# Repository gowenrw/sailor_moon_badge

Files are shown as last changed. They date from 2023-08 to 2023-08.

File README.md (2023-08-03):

# sailor_moon_badge

Sailor Moon Badge Artifacts

This is a DEFCON Indie badge created for DC31.

This is where all the files for the Badge will be stored.

This includes code and art and cad and fab files.  All the things.

## File Structure

This is the file structure of this repository

* [/](/README.md) - YOU ARE HERE
* [/art/](./art/) - Artwork and other graphics created by this project
  * [/art/inspiration/](./art/inspiration/) - Art and graphics pulled from other sources used as inspiration for this project
  * [/art/fonts/](./art/fonts/) - Fonts used in art and graphics
* [/code/](./code/) - All project related Code / Firmware
* [/docs/](./docs/) - Documentation created by this project including web pages
* [/eda/](./eda/) - Electronic Design Automation files (i.e. KiCad)
  * [/eda/sailor_moon/](./eda/sailor_moon/) - KiCad 6.x project folder for the future_badge PCB
* [/README.md](/README.md) - This File
* [/LICENSE](/LICENSE) - Currently set to MIT

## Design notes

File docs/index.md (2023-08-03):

---
layout: default
---

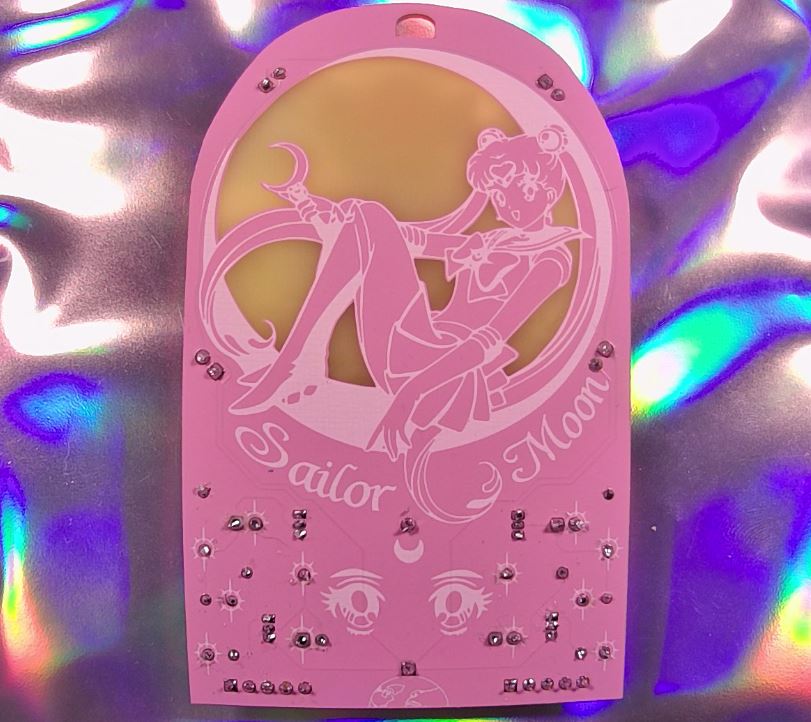
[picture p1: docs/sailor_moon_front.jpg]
sailor moon front


# Welcome

Welcome to the sailor moon badge website/repository.

This is where you will find all the details and files and instructions related to the DC31 sailor moon badge #badgelife.

# Story

I noticed at defcon 30 that there were no anime badges or cute badges I found appealing.

So, I wanted to make a cute sailor moon themed badge that was easy to assemble and could stand on its own to be displayed with figures and other collectables.

I think this badge turned out great and I hope everyone enjoys it.

-- Ninjician

---

# Details

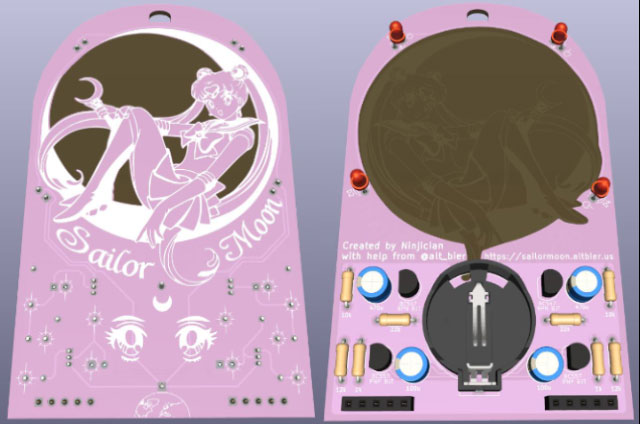
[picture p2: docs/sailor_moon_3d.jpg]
sailor moon 3d


The badge is designed with a simple easy to solder circuit that utilizes back lighting to highlight the art.

It uses female and male header pins on the bottom of the badge to make a stand that allows the badge to stand upright on a flat surface.

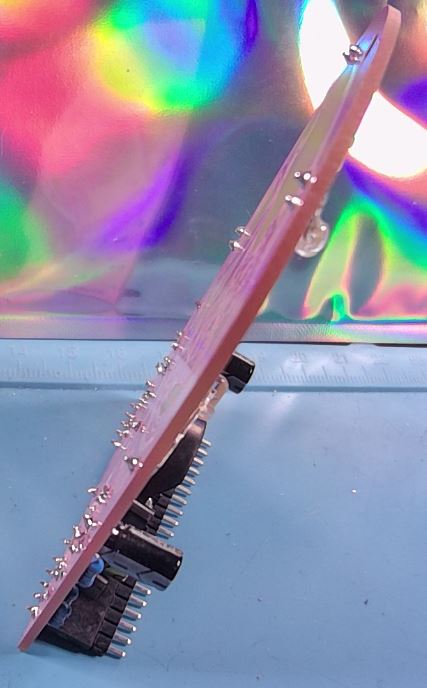
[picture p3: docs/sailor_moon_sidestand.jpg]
sailor moon side stand


While a few assembled badges will be available most will be provided as DIY solder kits.

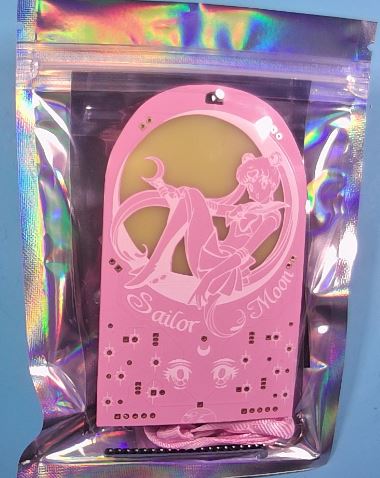
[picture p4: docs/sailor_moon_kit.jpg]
sailor moon kit


## The Circuit

The circuit is based on an astable multivibrator with the resistance and capacitance adjusted to produce the LED fade effect.

Here is the circuit schematic

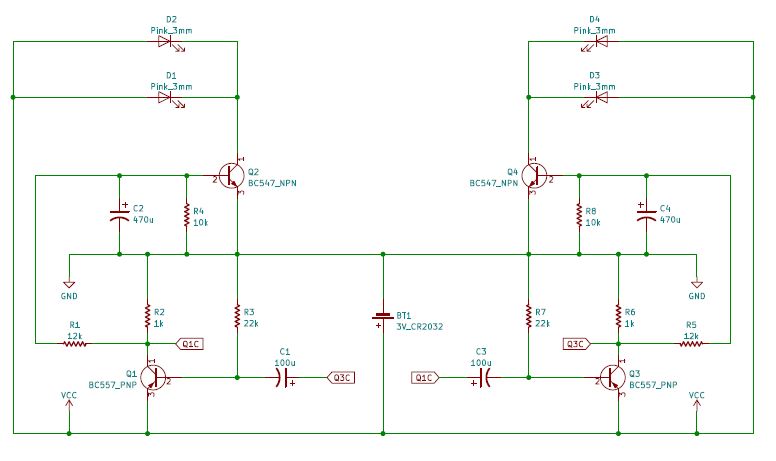
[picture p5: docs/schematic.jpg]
sailor moon schematic


## Kit Contents

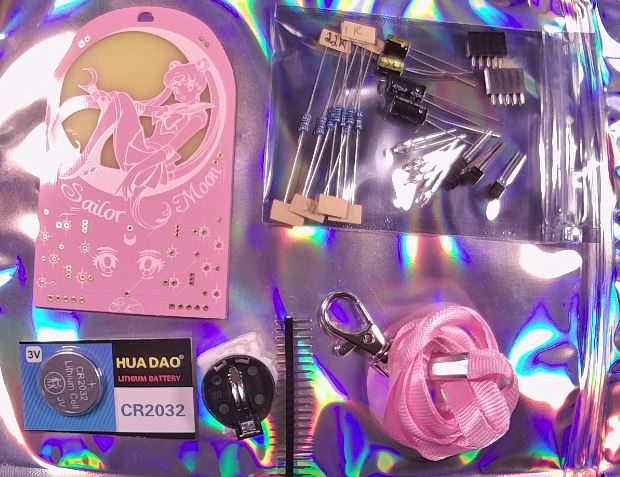
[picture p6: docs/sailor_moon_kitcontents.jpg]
sailor moon kit contents


The kit contains the following items:

* 1x PCB
* 1x Lanyard
* 1x 1x20 pin Male Header
* 1x CR2032 Battery Holder
* 1x CR2032 Battery
* 2x 1x5 pin Female Header
* 2x 22k ohm Resistor
* 2x 12k ohm Resistor
* 2x 10k ohm Resistor
* 2x 1k ohm Resistor
* 2x BC547 NPN BJT Transistor
* 2x BC557 PNP BJT Transistor
* 2x 100uF Polorized Capacitor
* 2x 470uF Polorized Capacitor
* 4x 3mm 2-pin Pink LED

# Kit Assembly

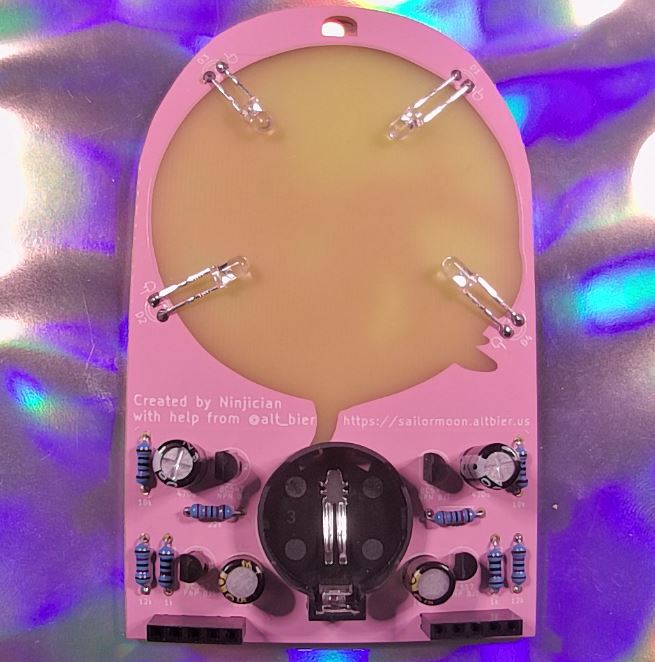
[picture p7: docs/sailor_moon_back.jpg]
sailor moon back


To assemble this badge you will place the through hole components into the pcb with the component body on the back of the pcb soldering the legs on the front of the pcb trimming them off at the top of the solder joints.

The back of the pcb has clear labels of where to place the components.

Take note of the direction of the transistors (which way the flat side faces) and make sure you place the proper transistor type in each space (the labels on the transistors are very small but are the only way to tell the difference between the two types).

Take note of the capacitor polarity inserting the negative leg into the negative hole which is indicated by solid silkscreen on the pcb.
The capacitors are labeled with the uF value and have a solid stripe on the negative leg side.

The resistors are bidirectional so it does not matter which way they are inserted as long as the proper resistance ohm value is used for each.  The pcb has the resistor values clearly labeled and while the resistors have a color code to show thier value, for your convinience the value has been written on the paper attached to them.

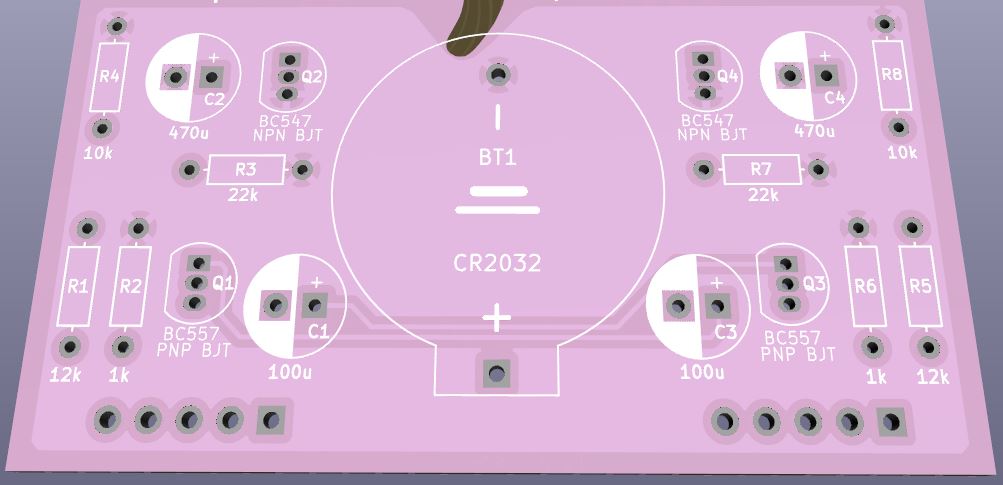
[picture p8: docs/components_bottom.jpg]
sailor moon components bottom


The LEDs should not be fully inserted instead leaving enough leg space for them to be bent over after soldering to appear in the back lit window of the pcb.

Take note of the direction of the LEDs as labeled on the PCB.  The label shows the short leg going into the square hole.

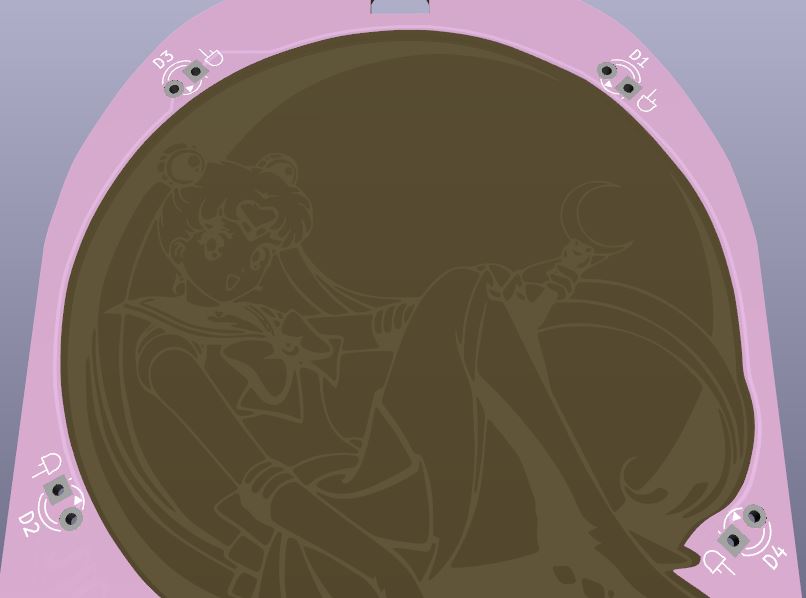
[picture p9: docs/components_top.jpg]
sailor moon components top


The female headers at the bottom are not part of the circuit and are thus optional.

The female headers allow for the insertion of the long male header strip to form a display stand for the badge.

# Repository

The repository containing all the artifacts for this badge is located [HERE](https://github.com/gowenrw/sailor_moon_badge)

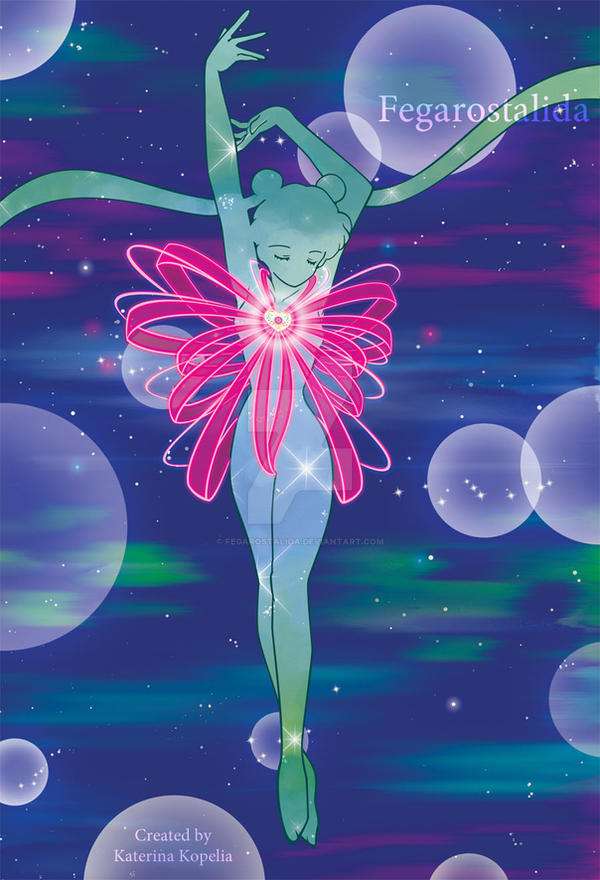
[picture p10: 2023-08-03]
art/inspiration/sailor_moon_supers_transformation_poster_by_fegarostalida_dc6exwj-fullview.jpg

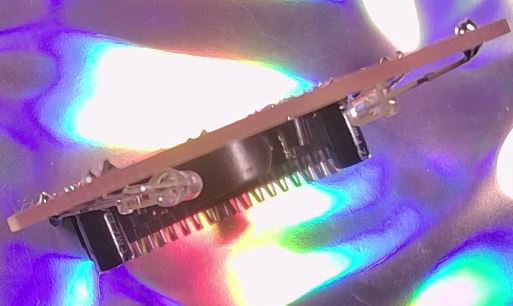
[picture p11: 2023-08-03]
docs/sailor_moon_topdown.jpg

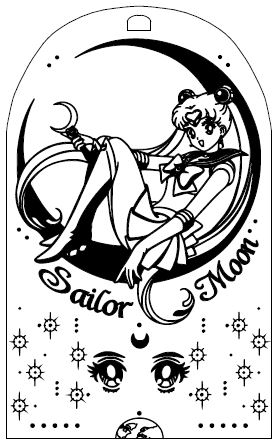
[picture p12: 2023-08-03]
docs/front_silk.jpg

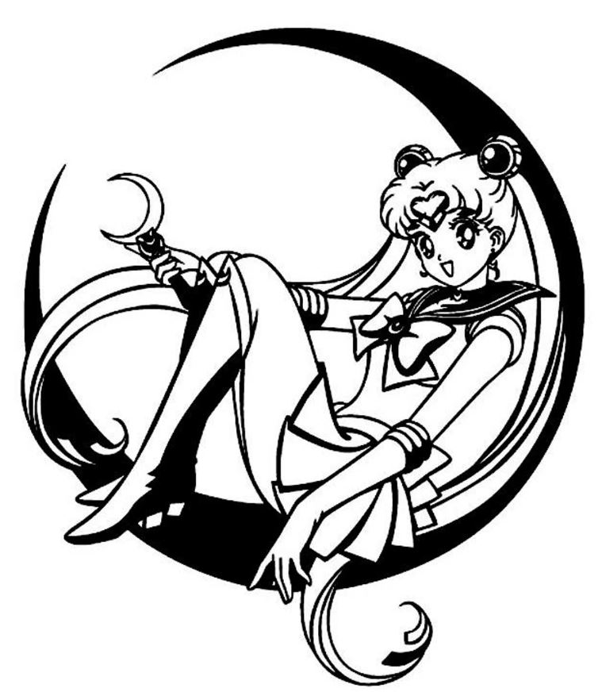
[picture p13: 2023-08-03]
art/inspiration/Circle.JPG

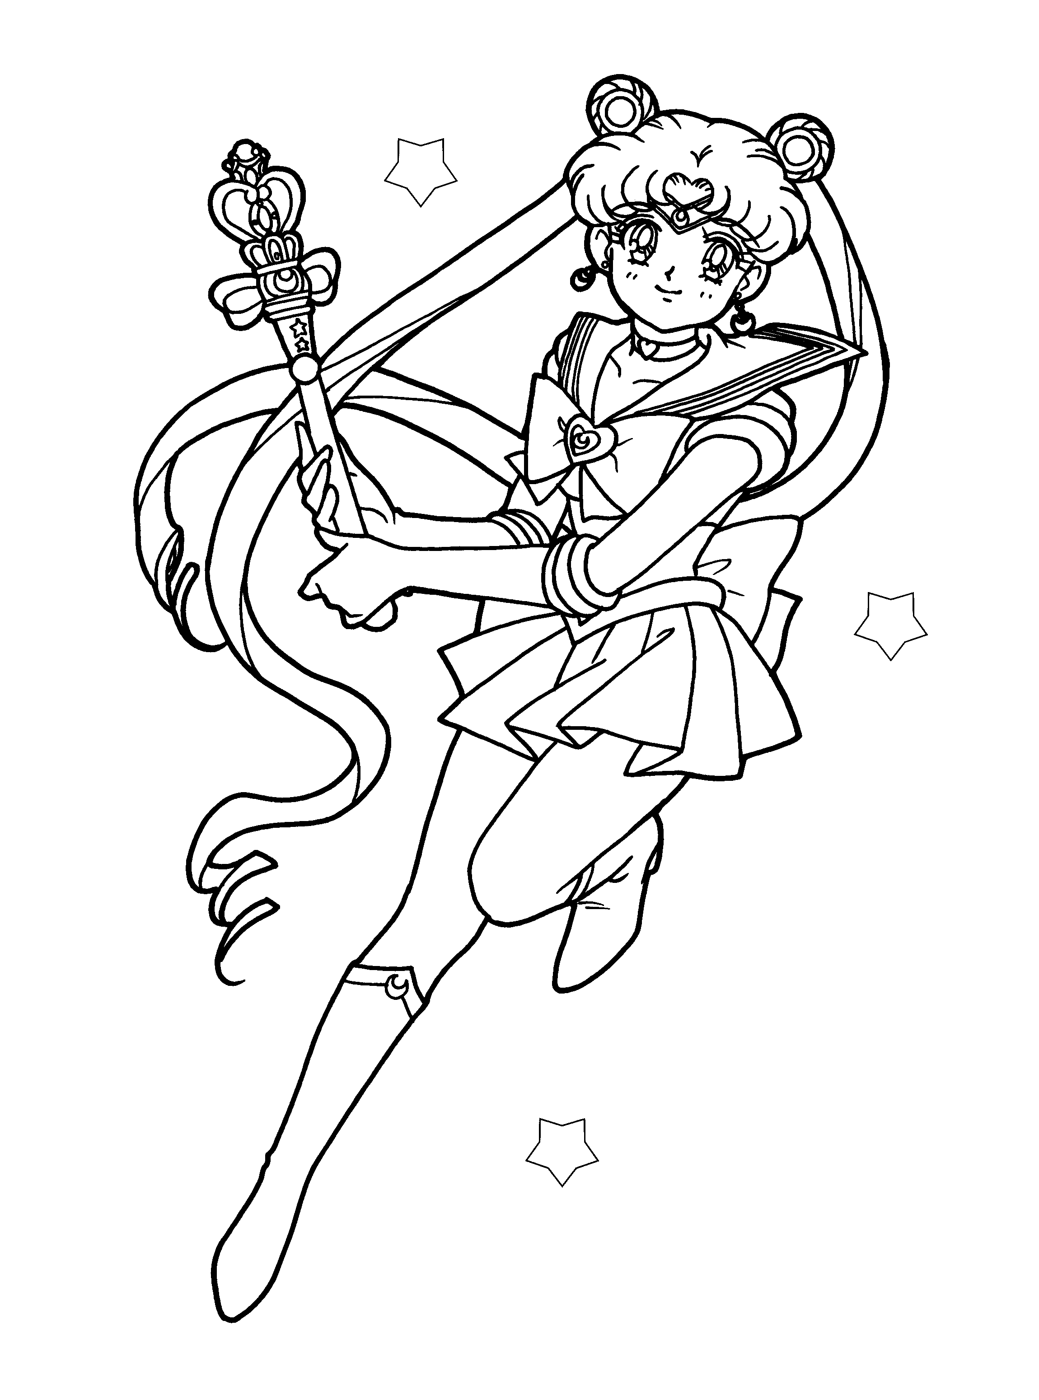
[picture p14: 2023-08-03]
art/inspiration/coloring-sailor-moon-50257.png

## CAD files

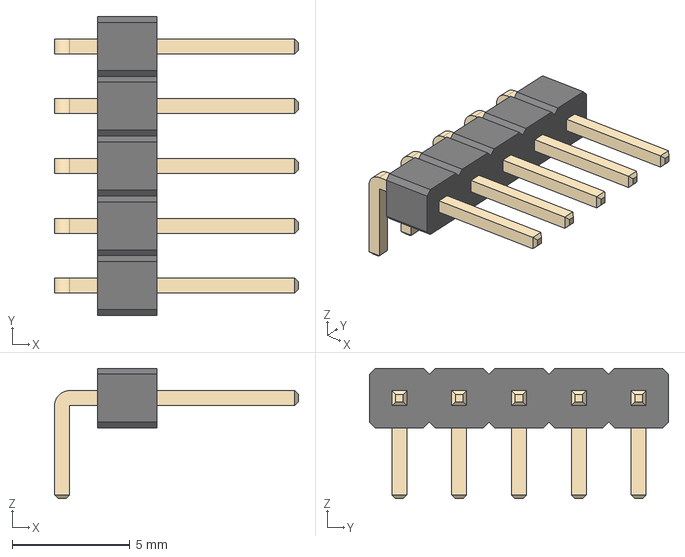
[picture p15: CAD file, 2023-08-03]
eda/sailor_moon/3d_models/PinHeader_1x05_P2.54mm_Horizontal.step
10.4 x 12.7 x 5.54 mm

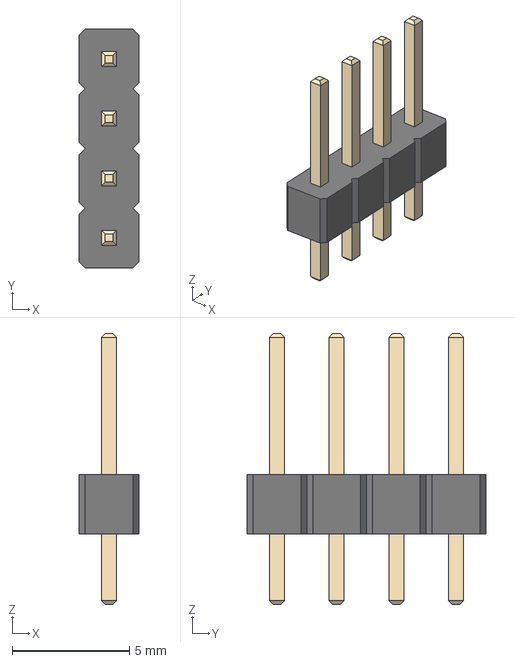
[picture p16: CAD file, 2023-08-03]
eda/sailor_moon/3d_models/PinHeader_1x04_P2.54mm_Vertical.step
2.54 x 10.2 x 11.5 mm

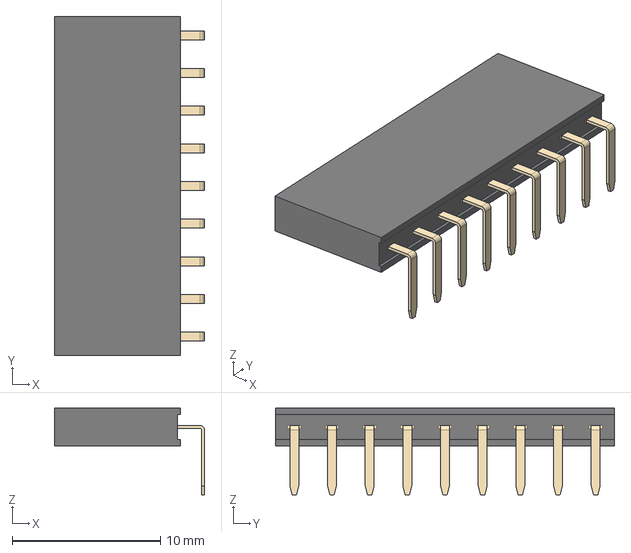
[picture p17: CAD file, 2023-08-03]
eda/sailor_moon/3d_models/PinSocket_1x09_P2.54mm_Horizontal.step
10.1 x 22.9 x 5.84 mm

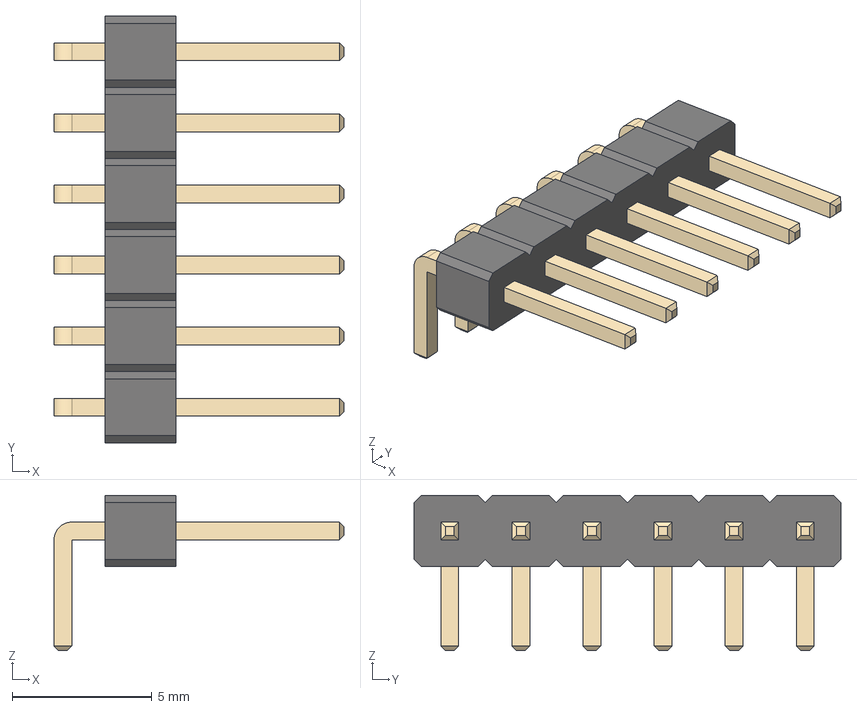
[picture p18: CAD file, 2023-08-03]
eda/sailor_moon/3d_models/PinHeader_1x06_P2.54mm_Horizontal.step
10.4 x 15.2 x 5.54 mm

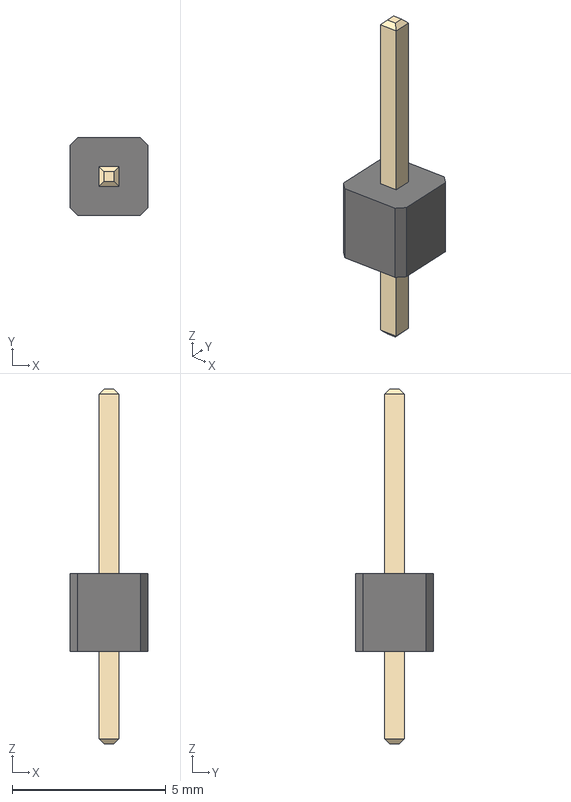
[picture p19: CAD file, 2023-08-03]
eda/sailor_moon/3d_models/PinHeader_1x01_P2.54mm_Vertical.step
2.54 x 2.54 x 11.5 mm

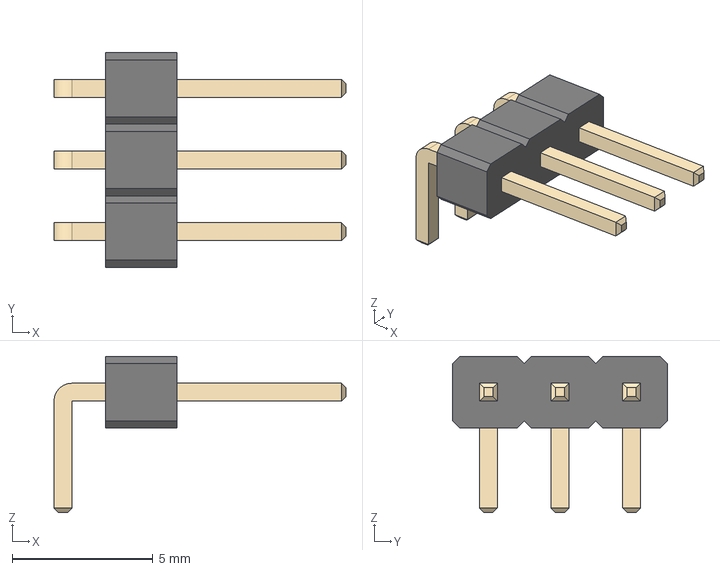
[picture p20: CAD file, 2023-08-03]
eda/sailor_moon/3d_models/PinHeader_1x03_P2.54mm_Horizontal.step
10.4 x 7.62 x 5.54 mm

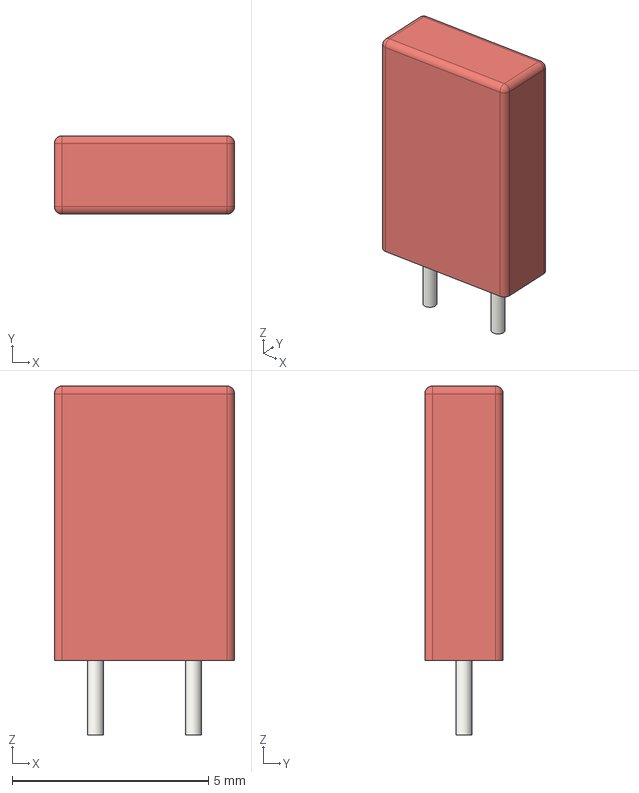
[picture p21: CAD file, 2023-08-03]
eda/sailor_moon/3d_models/C_Rect_L4.6mm_W2.0mm_P2.50mm_MKS02_FKP02.step
4.60 x 2.00 x 8.90 mm

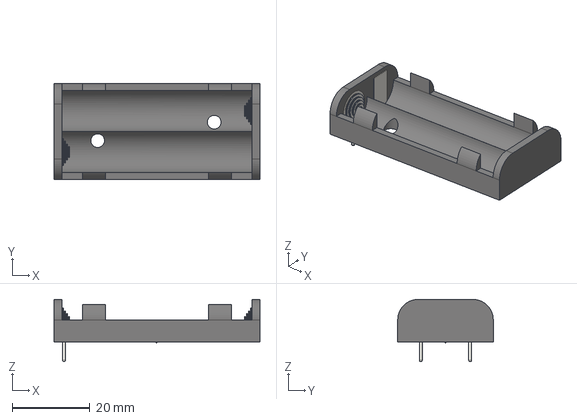
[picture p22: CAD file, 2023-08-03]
eda/sailor_moon/3d_models/BatteryHolder_2468_2xAAA.step
53.0 x 24.6 x 16.0 mm

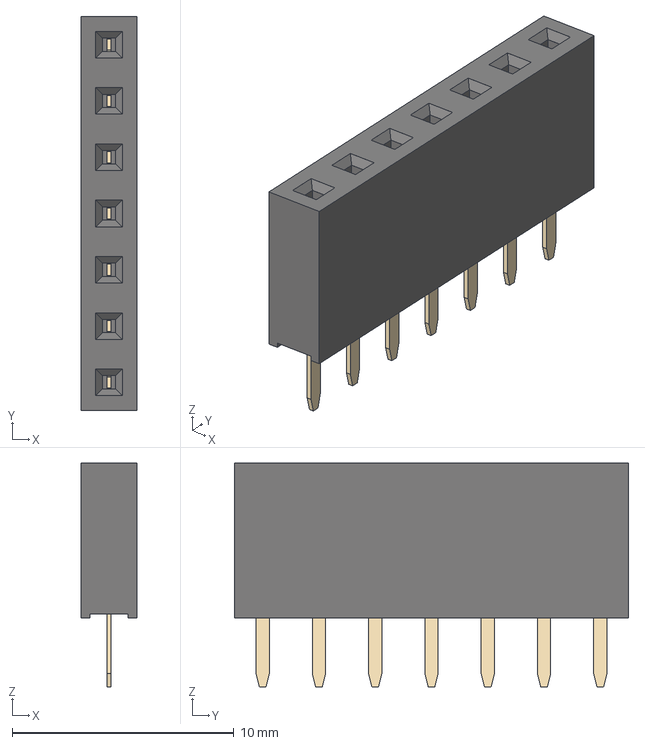
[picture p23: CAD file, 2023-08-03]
eda/sailor_moon/3d_models/PinSocket_1x07_P2.54mm_Vertical.step
2.54 x 17.8 x 10.1 mm

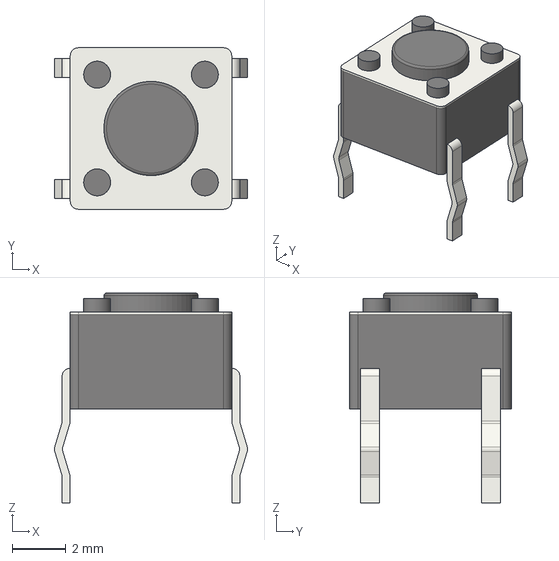
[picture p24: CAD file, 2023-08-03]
eda/sailor_moon/3d_models/SW_PUSH_6mm.step
7.17 x 6.00 x 7.80 mm

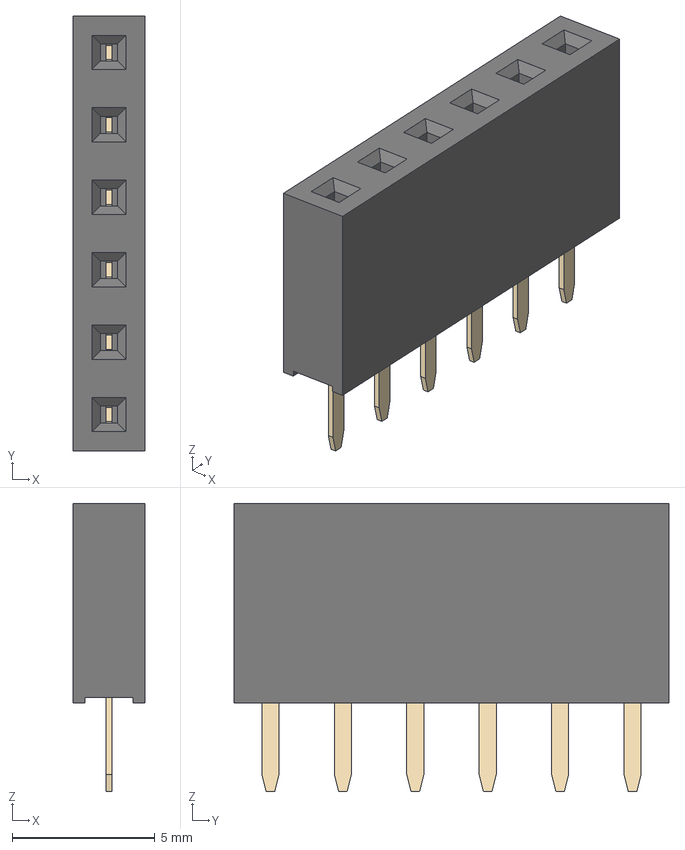
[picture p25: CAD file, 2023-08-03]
eda/sailor_moon/3d_models/PinSocket_1x06_P2.54mm_Vertical.step
2.54 x 15.2 x 10.1 mm

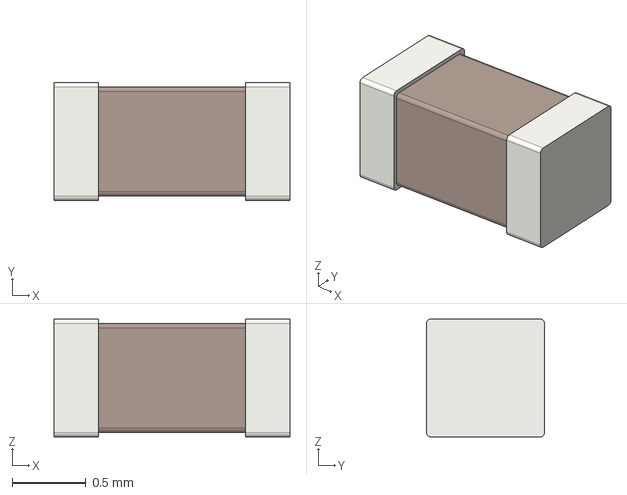
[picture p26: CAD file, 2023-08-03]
eda/sailor_moon/3d_models/C_0603_1608Metric.step
1.60 x 0.8 x 0.8 mm

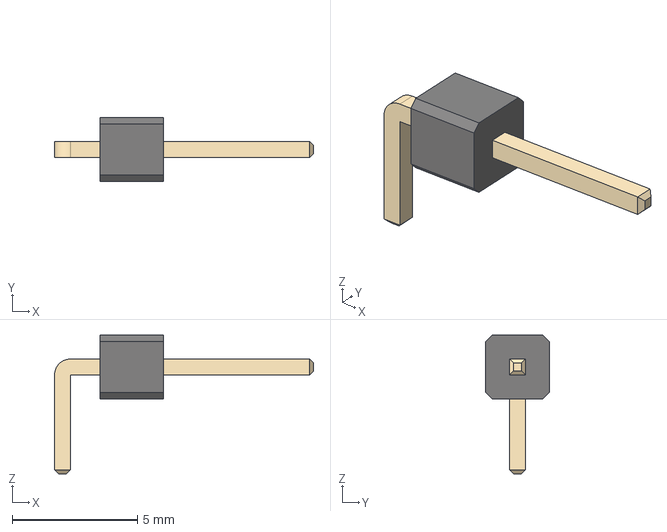
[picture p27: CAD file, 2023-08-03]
eda/sailor_moon/3d_models/PinHeader_1x01_P2.54mm_Horizontal.step
10.4 x 2.54 x 5.54 mm

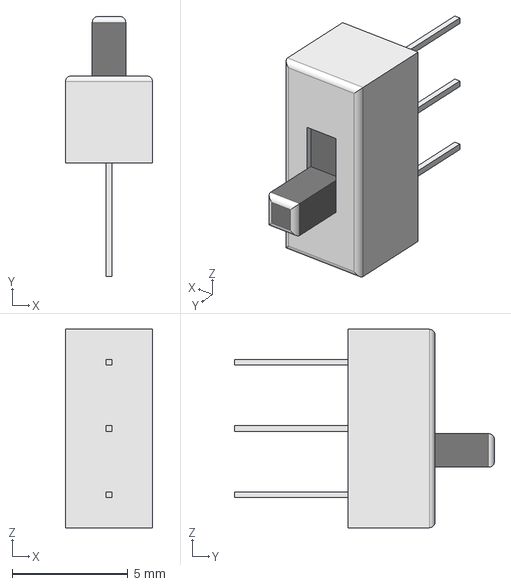
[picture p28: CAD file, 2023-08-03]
eda/sailor_moon/3d_models/SW_SS12D00G-Mini-SPDT-Slide-Switch-3pin-1P2T-2-Position-Toggle-Switch-3D.step
3.77 x 11.2 x 8.59 mm

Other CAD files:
eda/sailor_moon/3d_models/PinHeader_1x08_P2.54mm_Vertical.step
eda/sailor_moon/3d_models/PinSocket_1x07_P2.54mm_Horizontal.step
eda/sailor_moon/3d_models/PinHeader_1x02_P2.54mm_Horizontal.step
eda/sailor_moon/3d_models/BatteryHolder_2466_1xAAA.step
eda/sailor_moon/3d_models/Battery_Holder_3xAAA_Simple.step
eda/sailor_moon/3d_models/Battery_Holder_CR2032_BS-2-1.stp
eda/sailor_moon/3d_models/CP_Radial_D5.0mm_P2.00mm.step
eda/sailor_moon/3d_models/CP_Radial_D6.3mm_P2.50mm.step
eda/sailor_moon/3d_models/CUI_PXO7803-500-M-TR.step
eda/sailor_moon/3d_models/C_0805_2012Metric.step
eda/sailor_moon/3d_models/C_1206_3216Metric.step
eda/sailor_moon/3d_models/C_Disc_D3.0mm_W2.0mm_P2.50mm.step
eda/sailor_moon/3d_models/LED_0603_1608Metric.step
eda/sailor_moon/3d_models/LED_0603_1608Metric_Castellated.step
eda/sailor_moon/3d_models/LED_0805_2012Metric.step
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

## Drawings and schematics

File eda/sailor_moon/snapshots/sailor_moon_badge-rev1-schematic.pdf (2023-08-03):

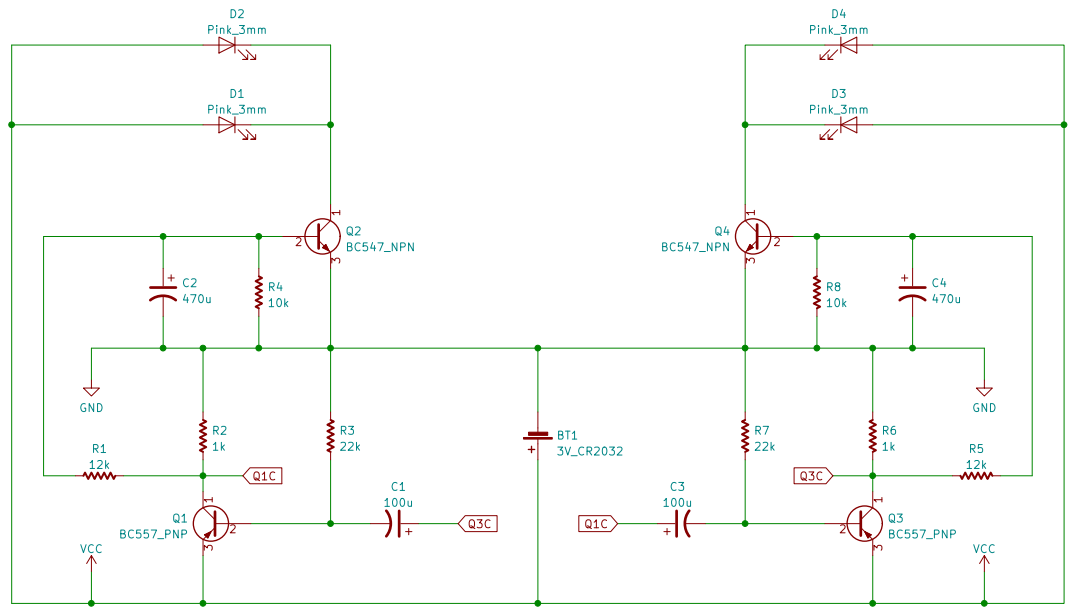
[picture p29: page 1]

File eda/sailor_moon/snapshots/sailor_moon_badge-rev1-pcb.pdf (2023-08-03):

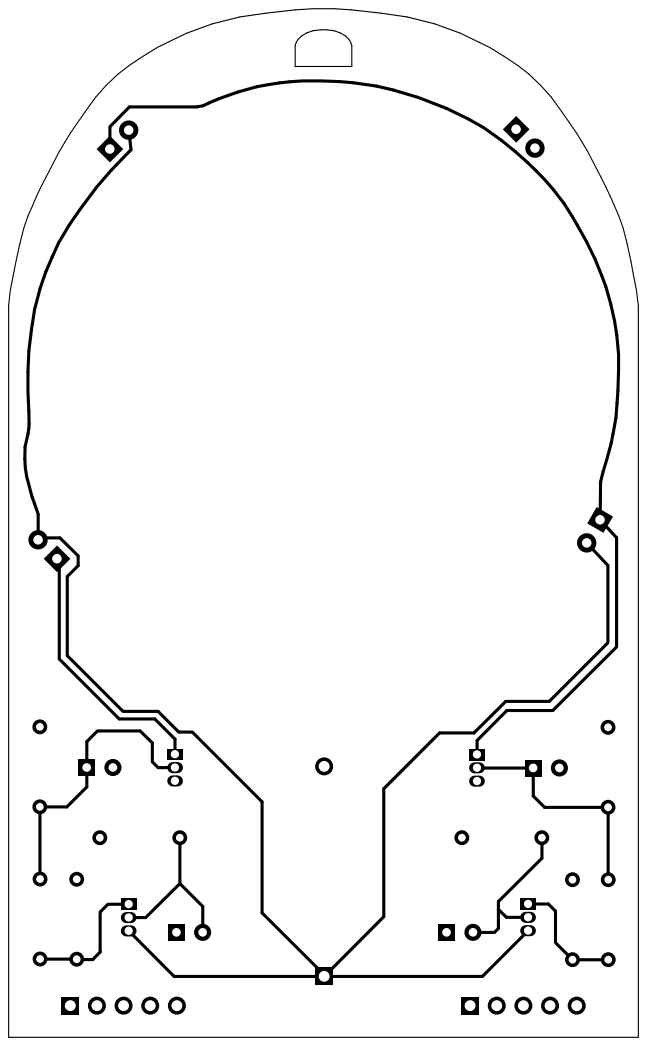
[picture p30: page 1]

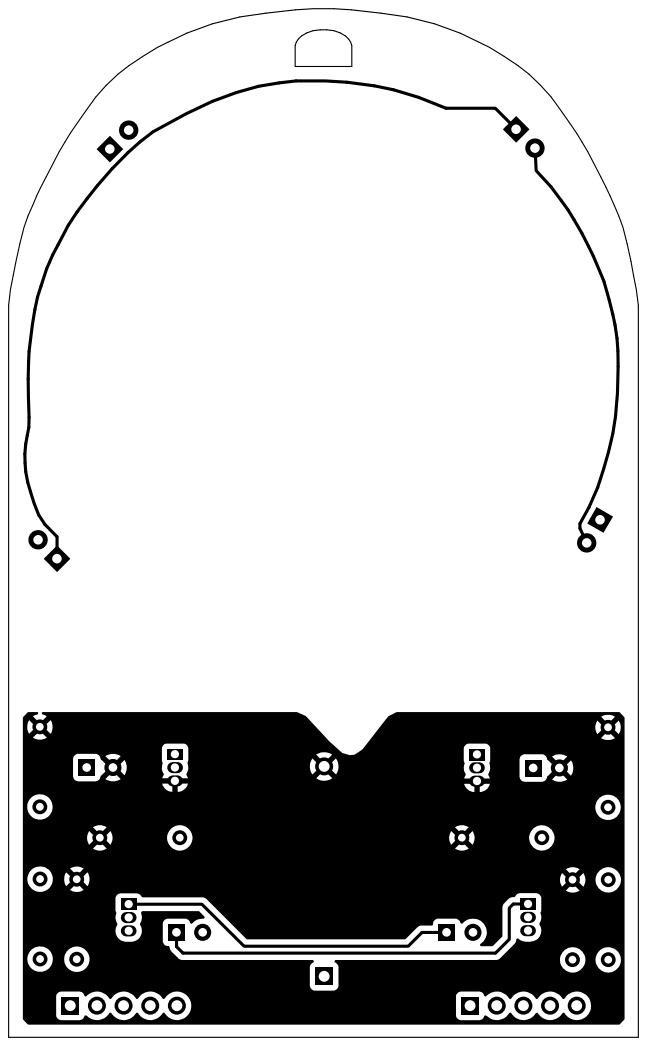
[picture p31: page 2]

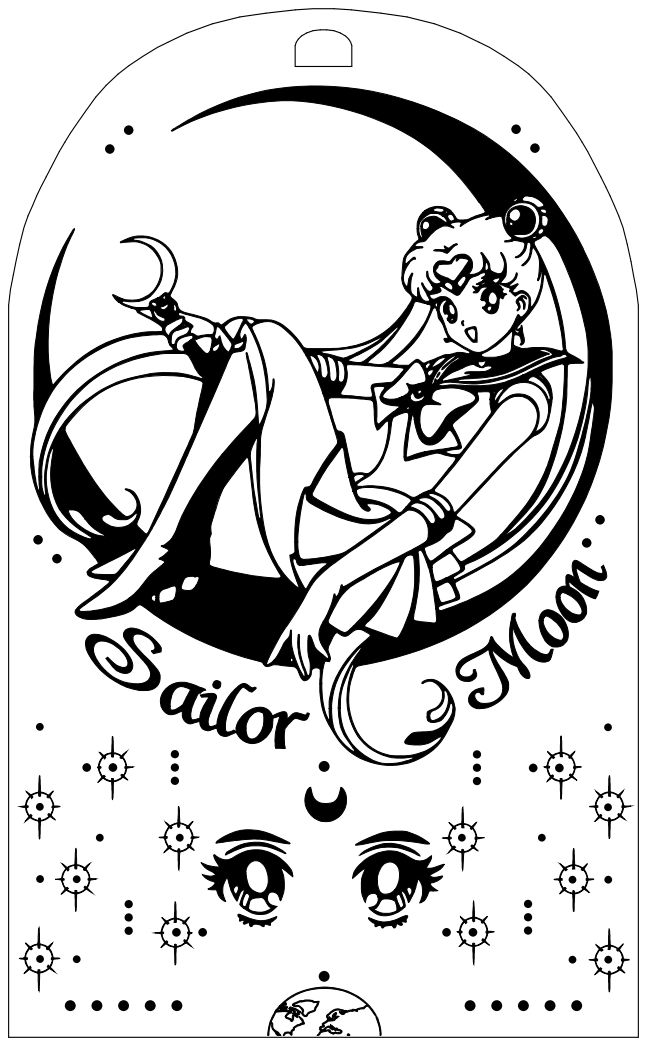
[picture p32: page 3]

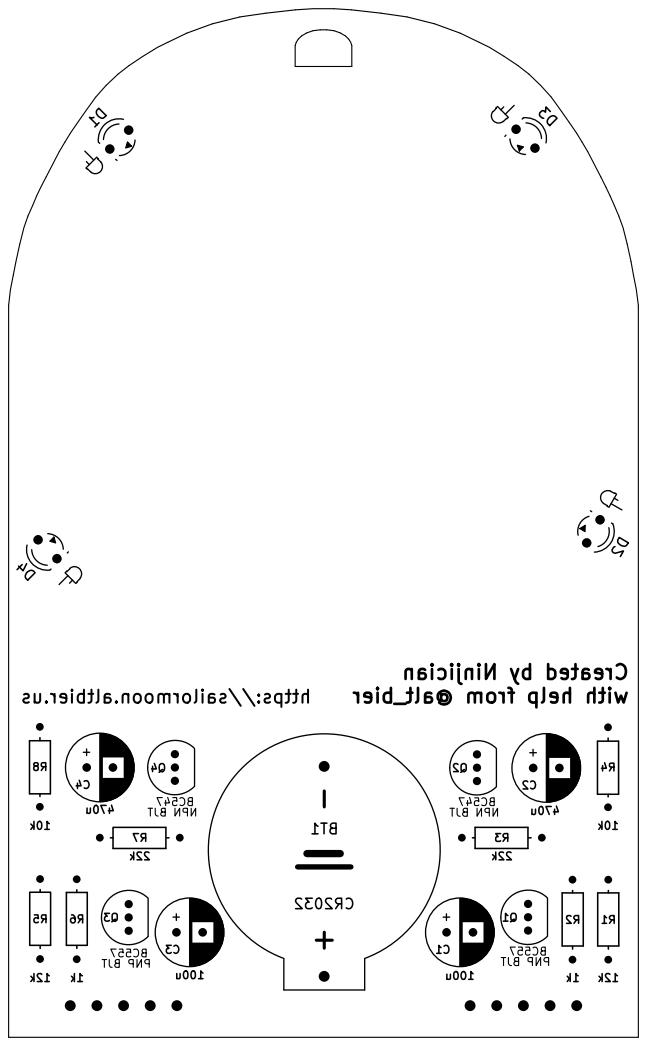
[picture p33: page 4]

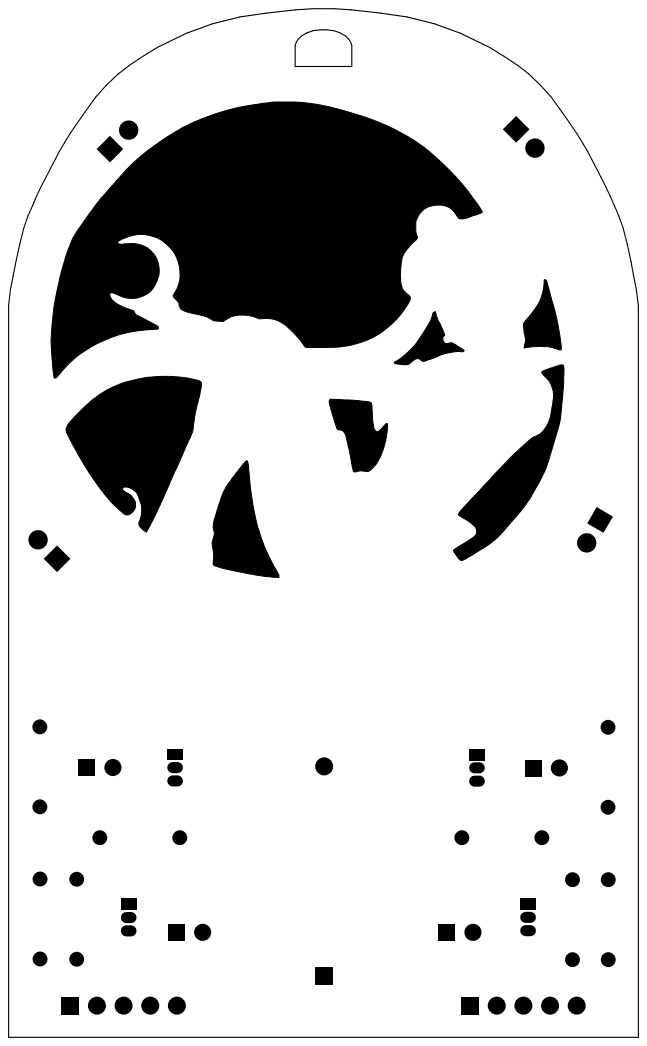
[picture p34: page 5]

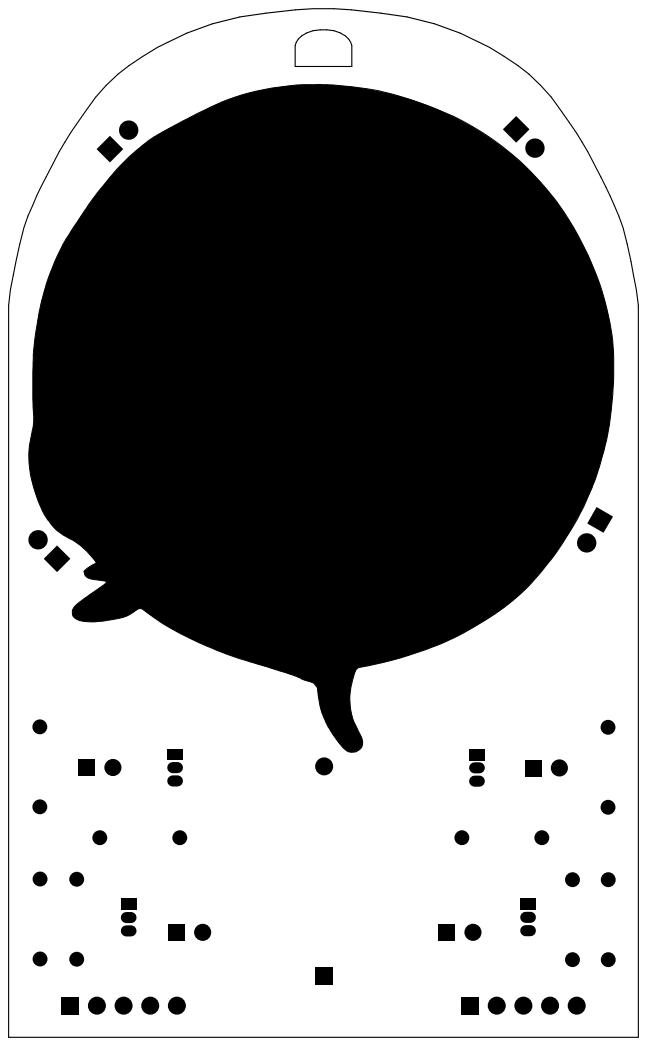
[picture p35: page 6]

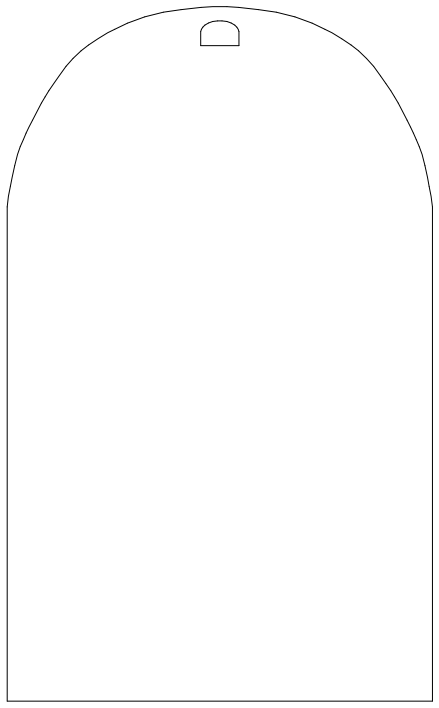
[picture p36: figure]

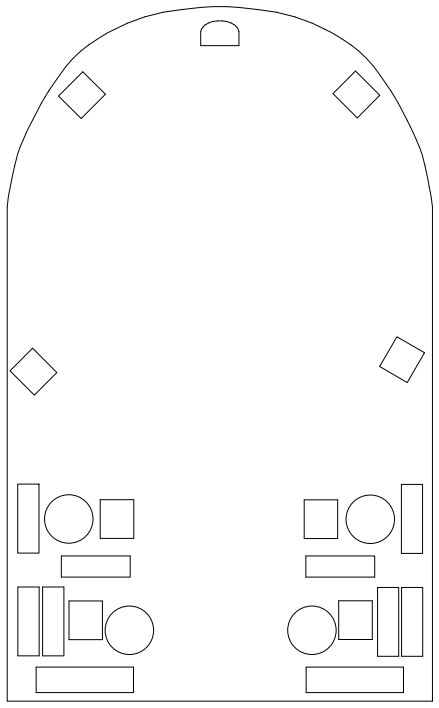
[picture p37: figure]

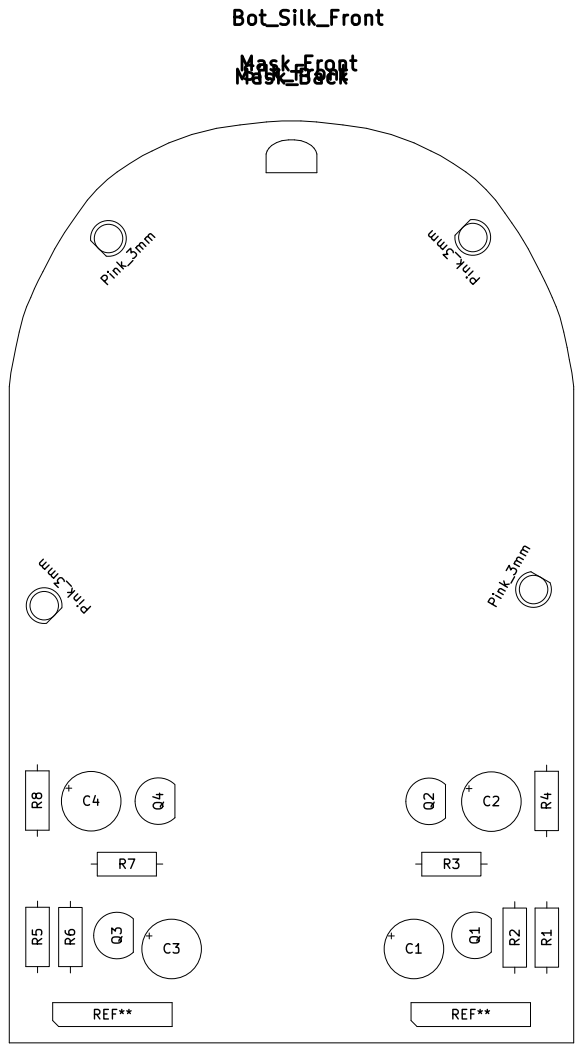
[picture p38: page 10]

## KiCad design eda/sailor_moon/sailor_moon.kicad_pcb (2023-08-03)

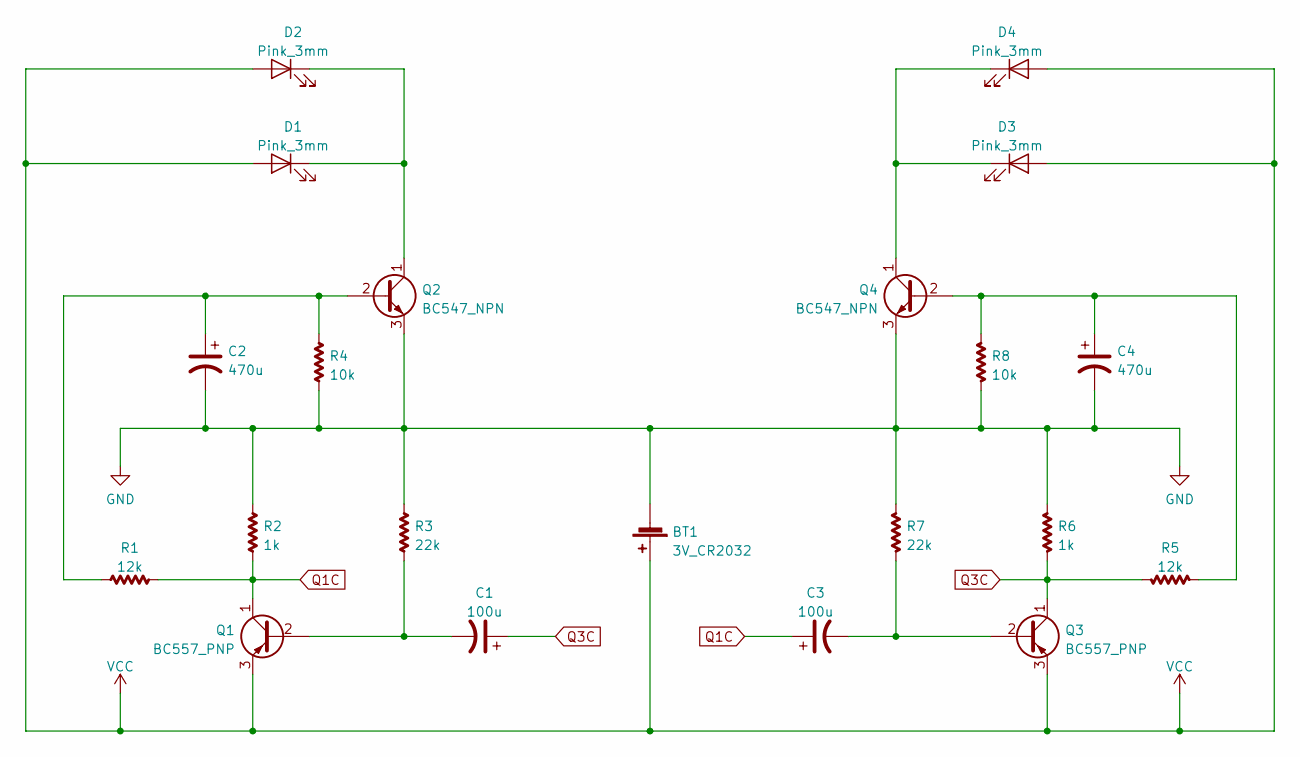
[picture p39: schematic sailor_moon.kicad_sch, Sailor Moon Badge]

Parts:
BT1: 3V_CR2032; BatteryHolder_CR2032-BS-2-1_Back_backsilk
C1, C3: 100u; CP_Radial_D6.3mm_P2.50mm_back
C2, C4: 470u; CP_Radial_D6.3mm_P2.50mm_back
D1, D2, D3, D4: Pink_3mm; LED_D3.0mm-2_back
Q1, Q3: BC557_PNP; Q_BC557_TO-92_back
Q2, Q4: BC547_NPN; Q_BC547_TO-92_back
R1, R5: 12k; R_Axial_DIN0207_L6.3mm_D2.5mm_P7.62mm_Horizontal_back
R2, R6: 1k; R_Axial_DIN0207_L6.3mm_D2.5mm_P7.62mm_Horizontal_back
R3, R7: 22k; R_Axial_DIN0207_L6.3mm_D2.5mm_P7.62mm_Horizontal_back
R4, R8: 10k; R_Axial_DIN0207_L6.3mm_D2.5mm_P7.62mm_Horizontal_back

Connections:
GND: BT1.2 (-), C2.2, C4.2, Q2.3 (E), Q4.3 (E), R2.1, R3.1, R4.2, R6.1, R7.1, R8.2
unnamed: C1.2, Q1.2 (B), R3.2
unnamed: C2.1, Q2.2 (B), R1.1, R4.1
unnamed: C3.2, Q3.2 (B), R7.2
unnamed: C4.1, Q4.2 (B), R5.1, R8.1
unnamed: D1.1 (K), D2.1 (K), Q2.1 (C)
unnamed: D3.1 (K), D4.1 (K), Q4.1 (C)
Q1C: C3.1, Q1.1 (C), R1.2, R2.2
Q3C: C1.1, Q3.1 (C), R5.2, R6.2
VCC: BT1.1 (+), D1.2 (A), D2.2 (A), D3.2 (A), D4.2 (A), Q1.3 (E), Q3.3 (E)

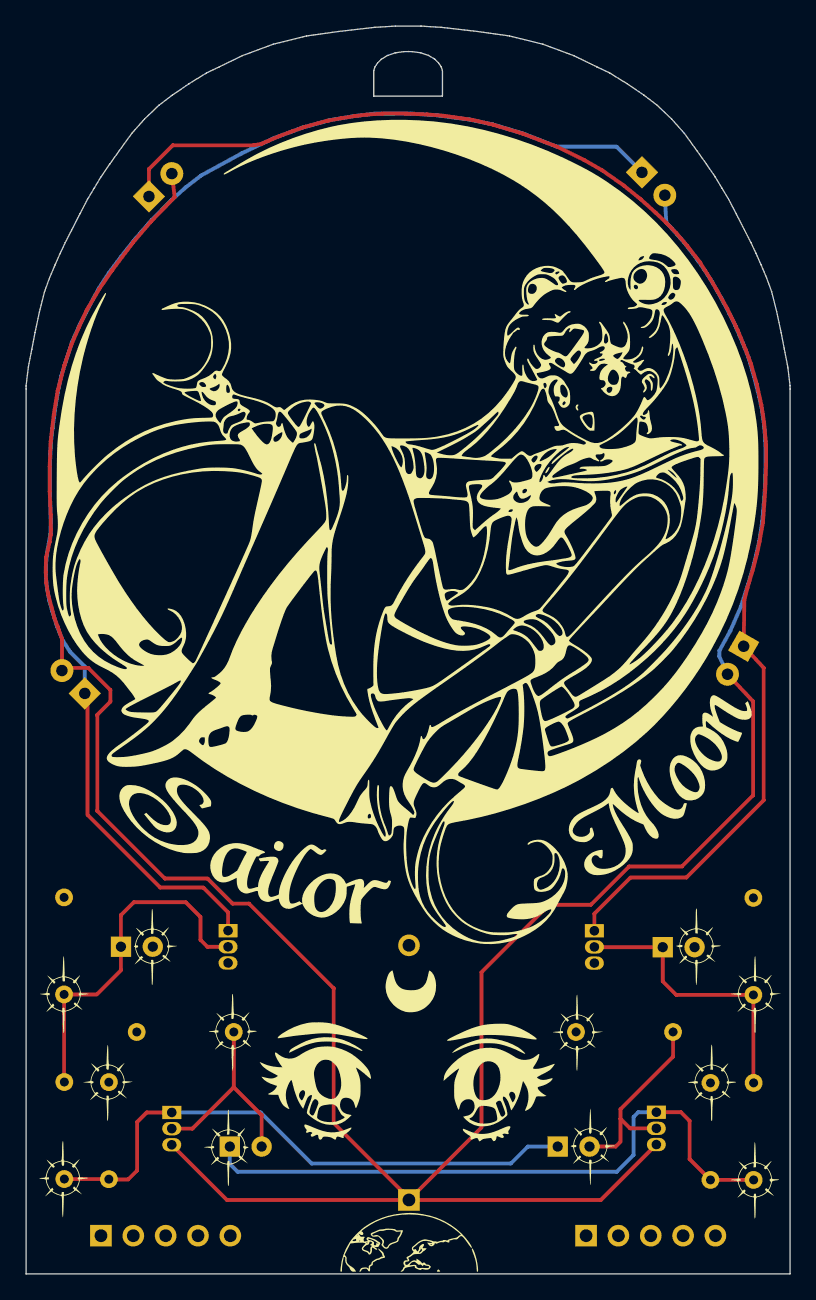
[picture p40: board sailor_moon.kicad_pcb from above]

Board: 2 copper layers, 60.0 x 98.0 mm, 25 parts (0 on the bottom side), 10 nets.

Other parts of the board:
Bot_Silk_Front: LOGO; 0_sailor_moon_bot_silkf_w60mm
Mask_Back: LOGO; 0_sailor_moon_maskb_w60mm
Mask_Front: LOGO; 0_sailor_moon_maskf_w60mm
Silk_Front: LOGO; 0_sailor_moon_silkf_w60mm

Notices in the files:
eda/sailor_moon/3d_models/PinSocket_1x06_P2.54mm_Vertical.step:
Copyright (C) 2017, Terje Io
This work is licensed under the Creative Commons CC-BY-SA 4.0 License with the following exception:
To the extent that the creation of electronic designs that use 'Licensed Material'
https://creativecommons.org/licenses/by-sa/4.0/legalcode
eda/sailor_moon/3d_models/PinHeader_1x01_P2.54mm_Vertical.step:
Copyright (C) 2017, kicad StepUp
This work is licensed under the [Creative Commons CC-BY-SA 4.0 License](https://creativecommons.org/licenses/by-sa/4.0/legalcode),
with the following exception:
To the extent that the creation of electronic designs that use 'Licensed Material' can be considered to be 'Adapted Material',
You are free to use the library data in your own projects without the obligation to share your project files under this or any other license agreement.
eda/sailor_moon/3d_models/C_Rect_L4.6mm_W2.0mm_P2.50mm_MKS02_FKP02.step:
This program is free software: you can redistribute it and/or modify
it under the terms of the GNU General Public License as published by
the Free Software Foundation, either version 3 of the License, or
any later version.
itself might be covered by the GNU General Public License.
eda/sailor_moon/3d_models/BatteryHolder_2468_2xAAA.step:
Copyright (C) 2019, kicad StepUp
